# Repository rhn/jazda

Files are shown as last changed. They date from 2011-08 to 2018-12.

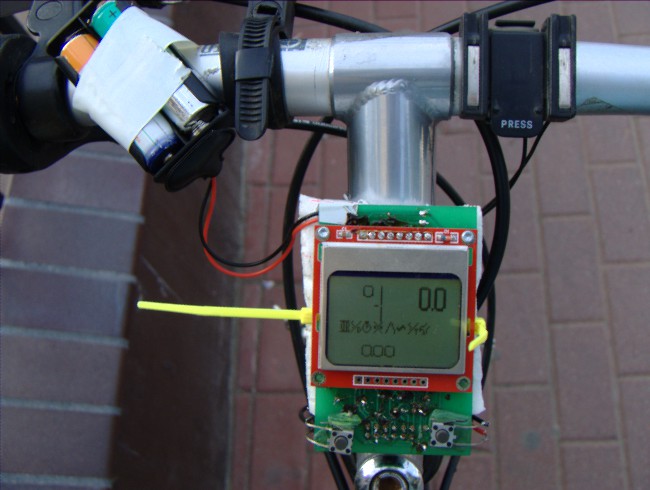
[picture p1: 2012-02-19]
.solderpad/photo.jpg

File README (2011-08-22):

Jazda is a bicycle computer based on AVR microcontrollers and mobile phone screens. The project covers both the software and hardware design, providing the source code and schematics.
Originally, it was built around AtTiny2313, now it's AtMega8. The microcontrollers were chosen because of their popularity and resistance to damage.
The other significant component is the screen. The project aims to be compatible with at least a few popular low-powered displays in the future, but at the moment only one is supported.

Project page:
https://github.com/rhn/jazda
Project wiki:
https://github.com/rhn/jazda/wiki/
Introduction, tutorial and hardware documents:
http://rhn.github.com/jazda/

FEATURES

5 speed measuring functions: current, max, average etc
Cadence measurement
Plotting as you ride
Low power consumption
DIY hardware
Modular code design

ASSEMBLY

For hardware needed to assemble the device, see docs/hardware
The schematics are available in Eagle format in eagle directory AND on the
project page (PNG format).
You will need an AVR programmer to upload the software to the chip!

SOFTWARE BUILDING

Linux:
To build & upload the software, you need:
- avr-gcc
- avr-libc
- avrdude
- Unix shell
1. Connect the AtMega8 chip to your computer using
your programmer (refer to the programmer's manual)
2. Consult avrdude manual to find your programmer's name (in this example, it's
"usbasp")
2. Issue the commands:
cd src
sh ../build.sh usbasp m8 main.c
replacing "usbasp" with your programmer's name

AUTHORS
rhn@porcupinefactory.org

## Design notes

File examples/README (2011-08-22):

Ladder of examples from the simplest to using all basic features of the project. Use to remember your skills and test your connections.

1: blink.c - blinking diodes
2: button.c - simple button input
3: buttonint.c - interrupt button input
4: lcd.c - lcd test pattern
5: lcd_counter.c - 3 + 4 + number display
6: lcd_status.c - interrupt splitter (for atmega8, optional)
7: lcd_drawing.c - advanced functions of the drawing library

To build an example, go to "examples" directory and issue the command:
sh ../build.sh controller_name m8 example_name.c

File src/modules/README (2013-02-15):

Module layout:

// Goodies:
#include "../common.h"

// Mandatory
#include "../actions.h"

// All exported names (currently all names) should be prepended with module name. Use "m_" prefix for best results.

// Redraw handler can have any name as long as it follows the signature:
void module_redraw(const uint8_t force);
// force decides whether a full screen update is necessary or the module can expect that it controlled the screen in the previous frame (for partial updates)
// This function can access the screen, but only 2 lower lines

// Action handling function
const module_actions_t* module_select(const uint8_t state);
// state notifies if the button was depressed (true) or released (false)
// return value: a structure of left-right button actions or NULL if they should stay unmodified.
// This function is run from an interrupt and therefore must not access the screen or do any expensive calculations

// Signature is the module icon. 8 bytes left-to-right, MSB=down
#define module_signature {0b10011001, 0b01011010, 0b00100100, 0b00011000, 0b00100100, 0b01011010, 0b10011001}

// Basic entry for module
#define module_record {&module_redraw, &module_select, module_signature}

// Last modification: add module_record reference inside base.c modules[] table.

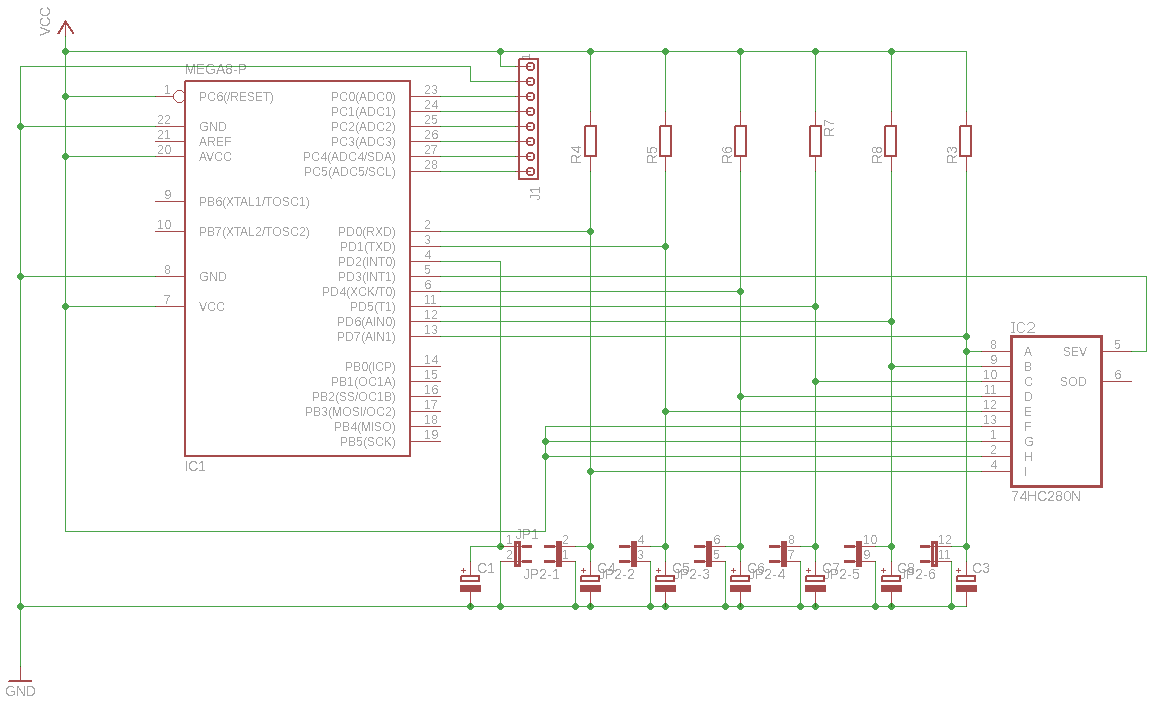
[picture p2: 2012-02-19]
.solderpad/schematic.png

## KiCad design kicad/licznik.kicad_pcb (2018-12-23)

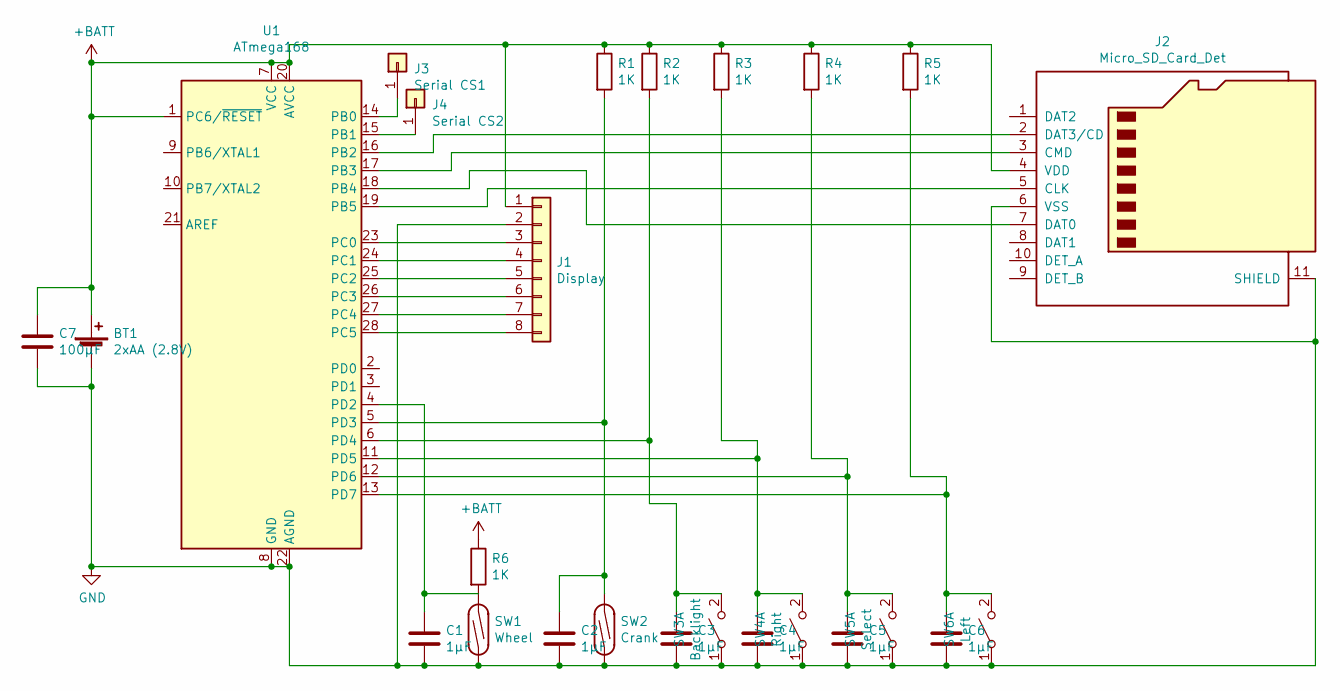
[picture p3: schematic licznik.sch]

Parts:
BT1: 2xAA (2.8V); PinHeader_1x02_P2.54mm_Vertical
C1, C2, C3: 1µF; C_0805_2012Metric_Pad1.15x1.40mm_HandSolder
C4, C5, C6: 1µF; C_0805_2012Metric
C7: 100µF; C_1210_3225Metric_Pad1.42x2.65mm_HandSolder
J1: Display; Nokia screen
J2: Micro_SD_Card_Det; SD_pins
J3: Serial CS1; PinHeader_1x01_P2.54mm_Horizontal
J4: Serial CS2; PinHeader_1x01_P2.54mm_Horizontal
R1, R2, R3, R4, R5, R6: 1K; R_0603_1608Metric
SW1: Wheel; PinHeader_1x02_P2.54mm_Horizontal
SW2: Crank; PinHeader_1x02_P2.54mm_Horizontal
SW3: Backlight; SW_PUSH_6mm_H5mm
SW4: Right; SW_PUSH_6mm_H5mm
SW5: Select; SW_PUSH_6mm_H5mm
SW6: Left; SW_PUSH_6mm_H5mm
U1: ATmega168; DIP-28_W7.62mm

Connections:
+BATT: BT1.1 (+), C7.1, J1.1, J2.4 (VDD), R1.1, R2.1, R3.1, R4.1, R5.1, R6.1, U1.1 (PC6/~RESET), U1.7 (VCC), U1.20 (AVCC)
GND: BT1.2 (-), C1.2, C2.2, C3.2, C4.2, C5.2, C6.2, C7.2, J1.2, J2.6 (VSS), J2.11 (SHIELD), SW1.1, SW2.1, SW3.1, SW4.1, SW5.1, SW6.1, U1.8 (GND), U1.22 (AGND)
unnamed: C1.1, R6.2, SW1.2, U1.4 (PD2)
unnamed: C2.1, R1.2, SW2.2, U1.5 (PD3)
unnamed: C3.1, R2.2, SW3.2, U1.6 (PD4)
unnamed: C4.1, R3.2, SW4.2, U1.11 (PD5)
unnamed: C5.1, R4.2, SW5.2, U1.12 (PD6)
unnamed: C6.1, R5.2, SW6.2, U1.13 (PD7)
unnamed: J1.3, U1.23 (PC0)
unnamed: J1.4, U1.24 (PC1)
unnamed: J1.5, U1.25 (PC2)
unnamed: J1.6, U1.26 (PC3)
unnamed: J1.7, U1.27 (PC4)
unnamed: J1.8, U1.28 (PC5)
unnamed: J2.2 (DAT3/CD), U1.16 (PB2)
unnamed: J2.3 (CMD), U1.17 (PB3)
unnamed: J2.5 (CLK), U1.19 (PB5)
unnamed: J2.7 (DAT0), U1.18 (PB4)
unnamed: J3.1, U1.14 (PB0)
unnamed: J4.1, U1.15 (PB1)

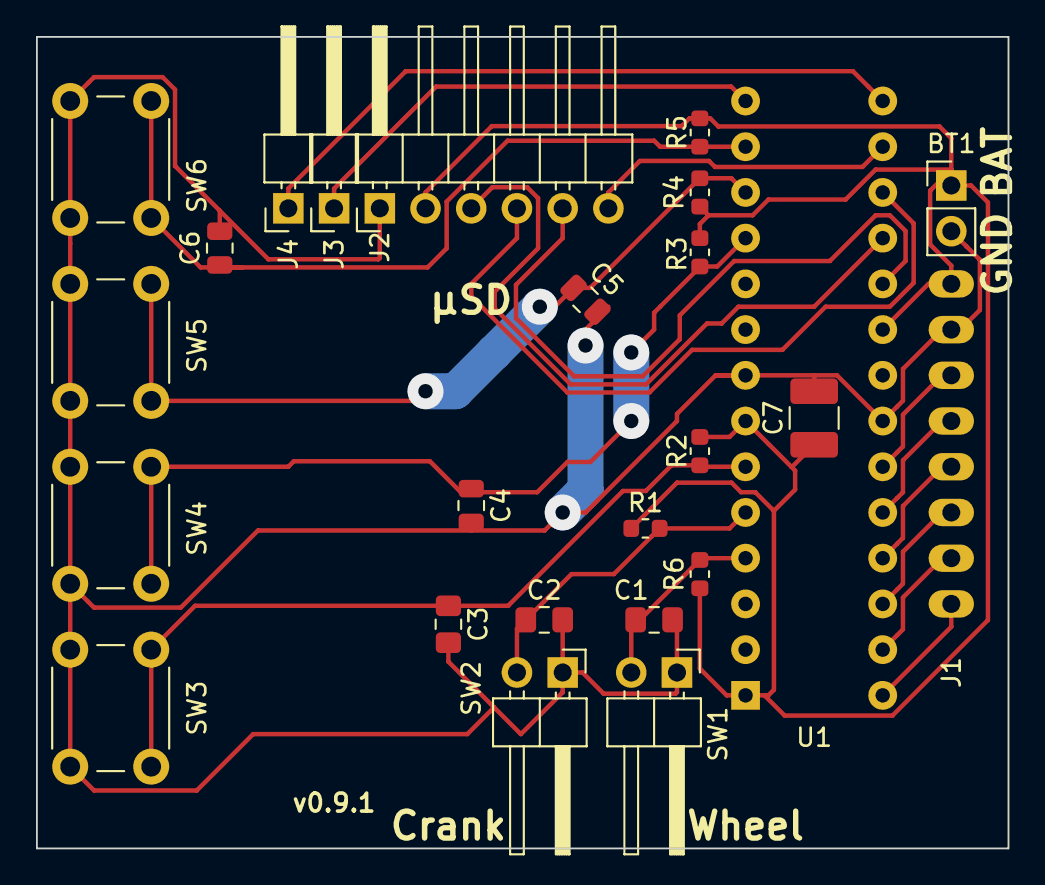
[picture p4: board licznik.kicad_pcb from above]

Board: 2 copper layers, 54.0 x 45.1 mm, 25 parts (1 on the bottom side), 20 nets.

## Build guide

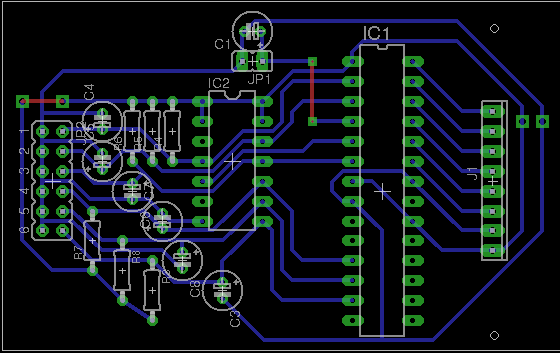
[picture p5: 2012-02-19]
.solderpad/board.png

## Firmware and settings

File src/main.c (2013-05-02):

/*
    Copyright 2011 rhn <gihu.rhn@porcupinefactory.org>
    Copyright 2013 Paweł Czaplejewicz

    This file is part of Jazda.

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
    You should have received a copy of the GNU General Public License
    along with Jazda.  If not, see <http://www.gnu.org/licenses/>.
*/

#define F_CPU 1000000L
#include <avr/io.h>
#include <avr/sleep.h>
#include <math.h>

#include "common.h"

#include "preferences.h"

#ifdef ATTINY2313
  #include "avr/attiny2313.c"
#else
  #ifdef ATMEGA8
    #include "avr/atmega8.c"
  #endif
#endif

/* imports depending on constants */
#include "display/pcd8544.c"
#include "display/bcd.c"
#include "display/drawing.c"


#include "lib/calculations.c"
#include "lib/timer.c"
#include "lib/plots.c"
#include "lib/modules.c"

// subsystems
#include "builtins/distance.c"
#ifdef STORAGE
    #include "builtins/storage.c"
#endif
#ifdef BACKLIGHT
    #include "dev/backlight.c"
#endif

// sensors (data/event capture)
#include "sensors/wheel.c"

#ifdef CRANK
    #include "sensors/crank.c"
#endif

// data display
#ifdef CADENCE
    #include "builtins/cadence.c"
#endif

#ifdef CURRENT_SPEED
    #include "builtins/speed.c"
#endif

// modules

#include "modules/base.c"

// debug builtin placed last to have access to all variables
#ifdef DEBUG
    #include "builtins/events.c"
#endif

#include "actions.c"
#include "signals.c" // must be included after its all callbacks

void main() __attribute__ ((noreturn));
void main(void) {
  setup_wheel_pulse();
  setup_buttons();
  setup_cpu();
  #ifdef STORAGE
      storage_setup();
      storage_load();
  #endif
  lcd_setup();
  lcd_init();
  
  #ifdef BACKLIGHT
      backlight_init();
  #endif
  #ifdef BACKLIGHT_VOLTAGE
     adc_init();
  #endif
  #ifdef LCD_CLEAN
     lcd_clean();
  #endif
  
  timer_initialize();

  // sleep enable bit
  MCUCR |= 1 << SE;
  // sleep mode
  MCUCR &= ~((1 << SM1) | (1 << SM0));

  sei();
  for (; ; ) {
    #ifdef CURRENT_SPEED
       speed_redraw();
    #endif
    #ifdef CADENCE
       cadence_redraw();
    #endif
    #ifdef DEBUG
       events_redraw();
    #endif
    module_redraw();
    nop_screen(); // FIXME: the screen doesn't immediately accept the last command

    /*
    send_raw_byte(emuintpinstate, true);
        send_raw_byte(emuintpinstate, true);
            send_raw_byte(emuintpinstate, true);
                send_raw_byte(emuintpinstate, true);*/
    sleep_mode();
  }
}

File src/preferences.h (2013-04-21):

/*
    Copyright 2011 rhn <gihu.rhn@porcupinefactory.org>
    Copyright 2013 Paweł Czaplejewicz

    This file is part of Jazda.

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
    You should have received a copy of the GNU General Public License
    along with Jazda.  If not, see <http://www.gnu.org/licenses/>.
*/

/* basic constants and switches, pin defines */

/* REQUIRES: none
*/

// - Inputs

#define PULSEDIR DDRD
#define PULSEPORT PORTD
#define PULSEPIN PD2

#define CRANKDIR DDRD
#define CRANKPORT PIND
#define CRANKPIN PD1

// -- Button interrupt

#define BUTTONDIR DDRD
#define BUTTONPORT PORTD
#define BUTTONPIN PD3

// -- Buttons

#define LEFTPIN PD7
#define LEFTPORT PIND
#define LEFTDIR DDRD

#define RIGHTPIN PD0
#define RIGHTPORT PIND
#define RIGHTDIR DDRD

#define SELECTPIN PD6
#define SELECTPORT PIND
#define SELECTDIR DDRD

#define BACKLIGHTBTNPIN PD4
#define BACKLIGHTBTNPORT PIND
#define BACKLIGHTBTNDIR DDRD

// - Output
// -- Screen

#define CLKDIR DDRC
#define CLKPORT PORTC
#define CLKPIN PC4

#define SDADIR DDRC
#define SDAPORT PORTC
#define SDAPIN PC3

#define D_CDIR DDRC
#define D_CPORT PORTC
#define D_CPIN PC2

#define SCEDIR DDRC
#define SCEPORT PORTC
#define SCEPIN PC0
   
#define RSTDIR DDRC
#define RSTPORT PORTC
#define RSTPIN PC1

// -- Backlight
#define BACKLIGHTDIR DDRC
#define BACKLIGHTPORT PORTC
#define BACKLIGHTPIN PC5

/* special options */
#define HIGH_PRECISION_CALCULATIONS // makes speed calculation 32-bit instead of truncating to 16
#define LONG_CALCULATIONS // makes calculations possible on longer data types
#define FRAC_BITS 10 // Fixed-point fraction for PULSE_DIST and SPEED_FACTOR. WARNING! modifying may lead to overflow errors and better precision (most likely just the former). Less then 8 is not recommended if LONG_SPEED is used
#define ONE_SECOND 3695 // in timer ticks, calibrated for 1MHz/256 // TODO: autocalculate

/* PREFERENCES */
// #define DEBUG

#define CRANK
#define CADENCE
#define STORAGE
#define BACKLIGHT
#define DISTANCE
#define CURRENT_SPEED
#define SPEED_VS_DISTANCE_PLOT
#define STOPWATCH
#define MAXSPEED
#define AVGSPEED
#define COMBINED_RESET
#define SPEED_VS_TIME_PLOT
#define CONFIG
// #define MOD_BACKLIGHT // backlight control via module
#define BACKLIGHT_BUTTON // backlight control via hw button
//#define BACKLIGHT_VOLTAGE // shows voltage along with backlight
#define LCD_CLEAN


#define METRIC_PULSE_DIST 2133L // millimeters

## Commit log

2010-08-11 Added schematic
2010-08-14 resolved some #define preferences mess, splt device-specific functions into separate files
    [attiny2313.h, main.c, preferences.h]
2010-08-16 added broken speed vs distance plot
    [main.c, preferences.h]
2010-08-16 fixed stop speed decrease
    [main.c]
2010-08-19 added a screen failure detection section
    [main.c]
2010-08-22 fixed screen failure mode
    [main.c]
2010-08-25 moved interrupts away to avr.h
2011-04-12 interrupt emulator works
2011-04-13 added drawing example, fixed drawing glitch
    [lcd_drawing.c, lcd_status.c]
2011-06-18 altered examples to mirror board, made main project compile
2011-06-19 fixed overflow in speed calculation, added comments
    [main.c]
2011-06-19 fixed debug print
2011-06-19 added missing files, dummy module, first working version of modules
    [main.c]
2011-06-21 failed attempt at modules
    [main.c]
2011-06-23 introduced extended timer
2011-06-23 added on_each_second timer and a stopwatch
2011-06-23 added broken maxspeed module
    [main.c, preferences.h]
2011-06-24 added stopwatch pausing, fixed speed timeouts
    [main.c]
2011-06-26 increased timer resolution
2011-06-26 calibrated for 1MHz internal clock@2.4V
2011-06-26 disentangled timers with help of a dummy module
2011-06-27 powersave: speed refresh only on update now
2011-07-23 updated examples & preferences to be compatible with prototype
2011-07-27 wrote a proper timer module
2011-07-27 moved timer to lib
2011-07-27 started separating basic speed/wheel functions
2011-07-28 untested - separated wheel and speed code
2011-07-30 broken timer in need of a rewrite
2011-07-30 rewritten timer to a naive but working implementation
2011-07-30 split speed and wheel into separate files
2011-07-31 fixed a situation with many timers set to the same instant
2011-08-20 moved wheel and crank to /sensors
2011-08-22 added eagle board and schematic files
    [small-clearance.brd, small-clearance.sch]
2011-09-01 updated board design
    [small-clearance.brd, v2.brd]
2012-02-19 added solderpad directory
2013-02-14 added ADC support with an example
2013-02-14 added battery status monitor
2013-02-14 reducing power usage at the cost of a small delay - turning on ADC for each battery reading
2013-02-15 added modules readme and voltage display
2013-04-21 backlight promoted to its own section, refactored constants, button-backlight added
2013-05-02 added number printing test case
2013-05-02 cleaned up number printing
2013-05-02 switched glyphs to using glyph_point_t
2018-11-19 Add crank pull up resistor
    [licznik.kicad_pcb, licznik.sch]
2018-11-19 Dimensions trim, reroute edy trace
    [licznik.kicad_pcb]
2018-11-23 Added elements for accelerometers, updated Nokia screen, shrunk the board
    [licznik.kicad_pcb]
2018-11-23 Moved buttons closer to the middle
    [licznik.kicad_pcb]
2018-11-23 Spaced around components for easy soldering
    [licznik.kicad_pcb]
2018-11-23 Added screen mounting holes
    [licznik.kicad_pcb]
2018-11-23 Added logo
    [licznik.kicad_pcb]
2018-11-23 Added silkscreen logos, placed silkscreen properly
    [licznik.kicad_pcb]
2018-11-23 Fix track moving over a hole
    [licznik.kicad_pcb]
2018-11-23 Marked version 0.9.1
    [licznik.kicad_pcb]
2018-11-30 Added more files just in case...
2018-11-30 Moved files to kicad/
    [licznik.kicad_pcb, licznik.sch]
2018-11-30 Removed Eagle board
    [small-clearance.sch, v2.brd]
2018-12-23 Allowed kicad to fix missing libraries
    [licznik.sch]
2018-12-23 PCB footprint: Set screen holes to 1mm
    [licznik.kicad_pcb]
2018-12-23 PCB: Adjust position of screen mounting holes
    [licznik.kicad_pcb]
2018-12-23 PCB: Fix screen hole placement, reduce board size
    [licznik.kicad_pcb]
2018-12-23 PCB: Stick out the IO header
    [licznik.kicad_pcb]
2018-12-23 PCB: Move holes description away from polluting the board
    [licznik.kicad_pcb]
2018-12-23 PCB: Use optional RTC capacitor
    [licznik.kicad_pcb, licznik.sch]
2018-12-23 Schematic: Added comments
    [licznik.sch]

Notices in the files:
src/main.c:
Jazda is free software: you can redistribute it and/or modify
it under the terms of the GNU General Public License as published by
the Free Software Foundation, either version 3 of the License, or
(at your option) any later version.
